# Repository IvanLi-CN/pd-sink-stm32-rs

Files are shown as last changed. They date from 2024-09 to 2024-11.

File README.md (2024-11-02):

# VoltageSpy

## Project Overview

VoltageSpy is a versatile power analysis tool, integrating a USB-PD (Power Delivery) emulator and real-time current, voltage, and power display functionality.

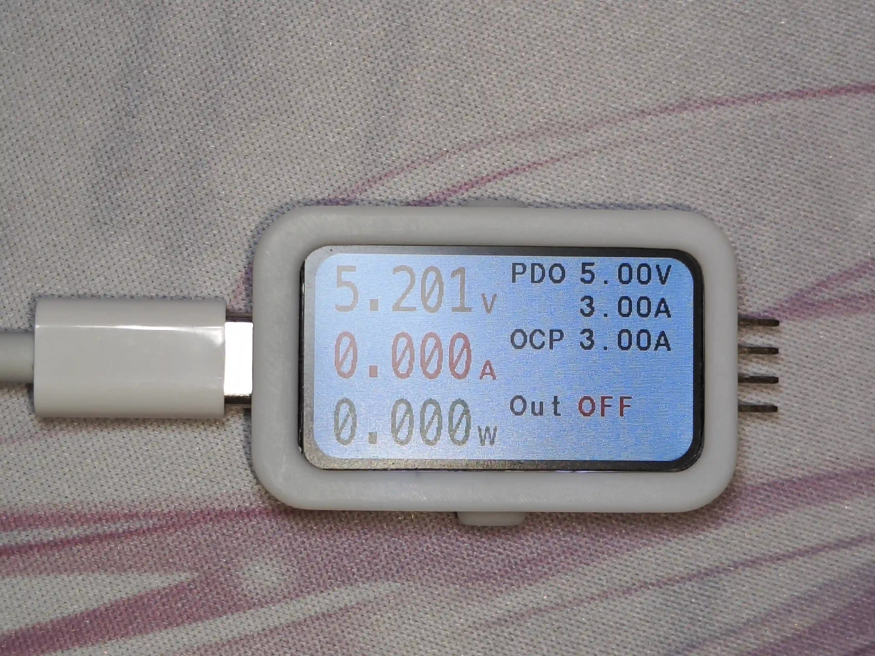
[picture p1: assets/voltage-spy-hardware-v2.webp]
hardware-v2


Originally intended for testing my other USB-C power project, this device can also serve as a temporary power supply tool. It supports voltage requests of 5V, 9V, 12V, 15V, 18V, and 20V.

The project is currently functional, but there are some additional features that I haven't had time to implement yet.

## Key Features

1. **PD Emulator**: Simulates various PD devices for testing and developing USB-C PD chargers and devices.
2. **Real-Time Display**: High-precision real-time monitoring and display of current, voltage, and power data.
3. **Overcurrent Protection**: Supports software overcurrent protection.
4. **Multi-Protocol Support**: In addition to PD, it also supports QC (Quick Charge) and other fast-charging protocols.

TODO:

- [ ] PWM Output
- [ ] Settings Memory (considering adding an EEPROM to achieve this)

## Technical Specifications

- Input Voltage Range: 0-20V
- Current Measurement Range: 0-5A
- Power Measurement Range: 0-100W
- Display: 1.47-inch TFT display (ST7789)
- Interface: USB-C -> 2.54mm pitch pin header
- Dimensions: 46mm x 26mm x 8.5mm

- Main Controller: STM32G071GBU6
- PD Sink Chip: HUSB238
- Current Sensor: INA226

- Firmware developed with Rust + embassy-stm32

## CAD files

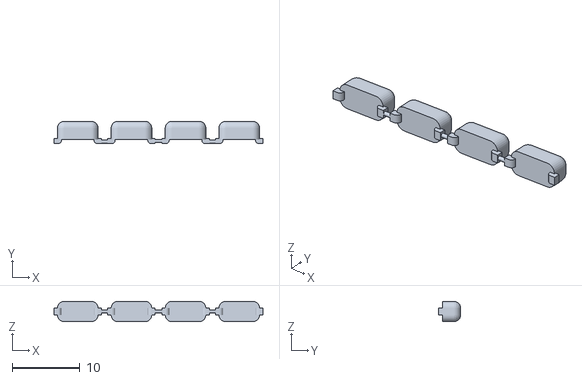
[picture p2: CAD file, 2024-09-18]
models/PDSinkShell-FourBtns.stl
30.8 x 3.30 x 3.00

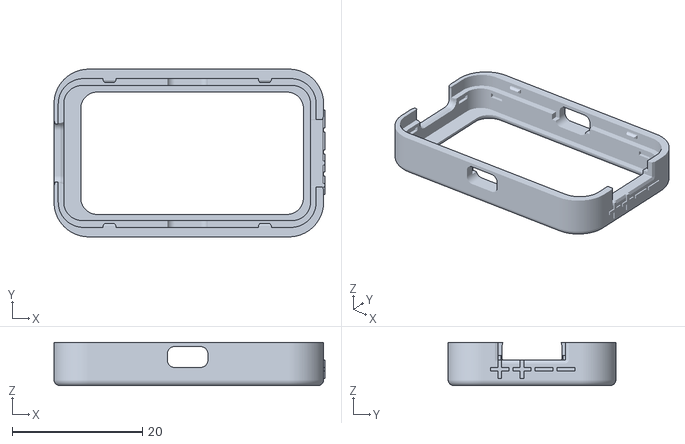
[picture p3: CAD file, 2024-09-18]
models/PDSinkShell-FrontCoverFusion.stl
41.6 x 25.7 x 6.64

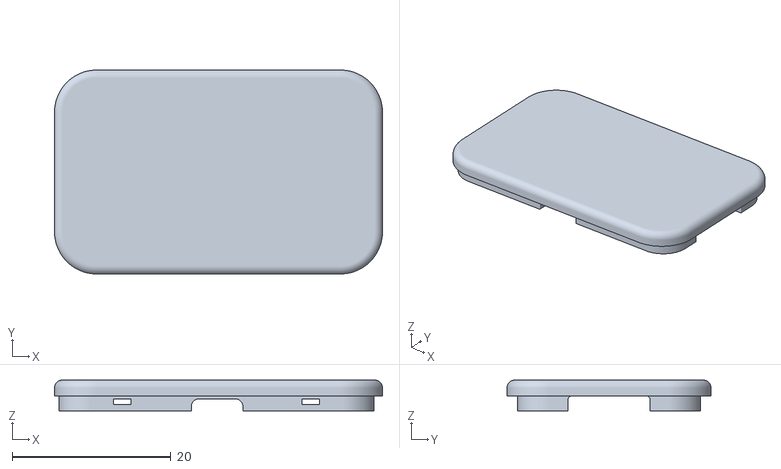
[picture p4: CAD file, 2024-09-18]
models/PDSinkShell-BackCover.stl
41.4 x 25.7 x 3.90

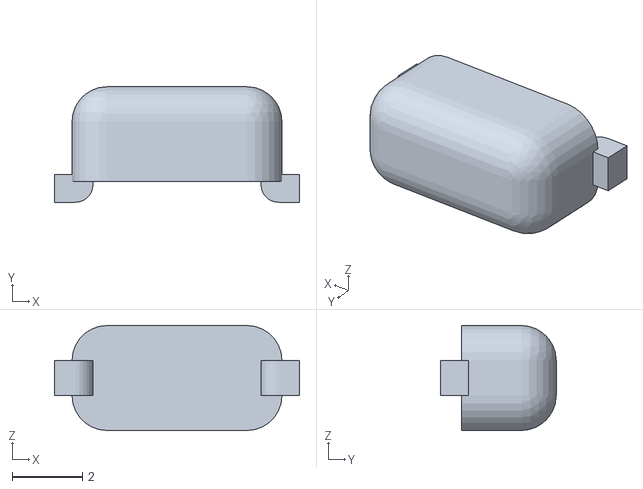
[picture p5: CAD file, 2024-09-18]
models/PDSinkShell-Button.stl
7.00 x 3.30 x 3.00

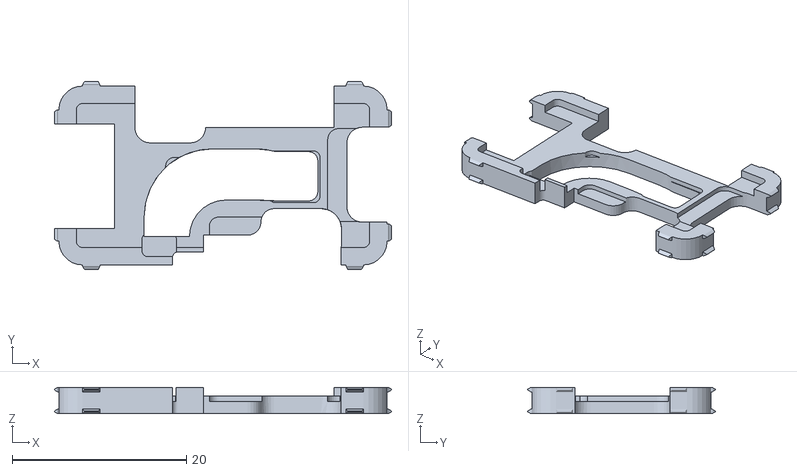
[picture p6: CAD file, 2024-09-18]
models/PDSinkShell-MiddleSpacer.stl
38.7 x 21.5 x 3.00

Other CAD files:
models/PDSinkShell-Button_Copy.stl

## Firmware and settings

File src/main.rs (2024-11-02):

#![no_std]
#![no_main]

use button::Button;
use combined_filter::CombinedFilter;
use controller::Controller;
use display::Display;
use embassy_embedded_hal::shared_bus::{
    asynch::{i2c::I2cDevice, spi::SpiDevice},
    I2cDeviceError,
};
use embassy_executor::Spawner;
use embassy_futures::select::{select3, Either3};
use embassy_stm32::{
    bind_interrupts,
    exti::ExtiInput,
    gpio::{Level, Output, OutputType, Pull, Speed},
    i2c::{self, I2c},
    mode, peripherals,
    spi::{self, Spi},
    time::{khz, Hertz},
    timer::simple_pwm::{PwmPin, SimplePwm},
};
use embassy_sync::{blocking_mutex::raw::CriticalSectionRawMutex, mutex::Mutex};

use defmt_rtt as _;
use embassy_time::{Duration, Ticker};
use husb238::{Command, Husb238};
use ina226::{DEFAULT_ADDRESS, INA226};
use output_controller::OutputController;
// global logger
use panic_probe as _;

use shared::{
    AVAILABLE_VOLT_CURR_MUTEX, BTN_A_STATE_CHANNEL, BTN_B_STATE_CHANNEL, DISPLAY, OCP_MUTEX,
    PDO_PUBSUB,
};
use st7789::{self, ST7789};
use static_cell::StaticCell;
use types::{AvailableVoltCurr, ST7789Display, SpiBus};

mod button;
mod controller;
mod display;
mod exponential_moving_average;
mod font;
mod output_controller;
mod shared;
mod types;
mod combined_filter;

static SPI_BUS_MUTEX: StaticCell<Mutex<CriticalSectionRawMutex, SpiBus>> = StaticCell::new();
static HUSB238_I2C_MUTEX: StaticCell<Mutex<CriticalSectionRawMutex, I2c<'_, mode::Async>>> =
    StaticCell::new();

bind_interrupts!(struct Irqs {
    I2C1 => i2c::EventInterruptHandler<peripherals::I2C1>, i2c::ErrorInterruptHandler<peripherals::I2C1>;
});

// This marks the entrypoint of our application.

#[embassy_executor::main]
async fn main(spawner: Spawner) {
    let p = embassy_stm32::init(Default::default());

    defmt::println!("Hello, world!");

    let out_ctl_pin = Output::new(p.PA8, Level::Low, Speed::Low);
    let mut output_controller = OutputController::new(out_ctl_pin);

    let mut config = spi::Config::default();
    config.frequency = Hertz(16_000_000);
    let spi = Spi::new_txonly(p.SPI1, p.PA5, p.PA7, p.DMA1_CH1, config); // SCK is unused.
    let spi: Mutex<CriticalSectionRawMutex, _> = Mutex::new(spi);
    let spi = SPI_BUS_MUTEX.init(spi);

    // init display

    let cs_pin = Output::new(p.PA4, Level::High, Speed::High);
    let dc_pin = Output::new(p.PA15, Level::Low, Speed::High);
    let rst_pin = Output::new(p.PA12, Level::Low, Speed::High);

    let spi_dev = SpiDevice::new(spi, cs_pin);

    let st7789: ST7789Display = ST7789::new(st7789::Config::default(), spi_dev, dc_pin, rst_pin);
    let mut _display = Display::new(st7789);

    _display.init().await.unwrap();

    let mut display = DISPLAY.lock().await;
    *display = Some(_display);
    drop(display);

    // init backlight

    let blk_pin = PwmPin::new_ch3(p.PB6, OutputType::PushPull);

    let mut blk_tim = SimplePwm::new(
        p.TIM1,
        None,
        None,
        Some(blk_pin),
        None,
        khz(1),
        embassy_stm32::timer::low_level::CountingMode::EdgeAlignedUp,
    );

    blk_tim.ch3().enable();
    blk_tim.ch3().set_duty_cycle_percent(50);

    let i2c = I2c::new(
        p.I2C1,
        p.PB8,
        p.PB7,
        Irqs,
        p.DMA1_CH3,
        p.DMA1_CH4,
        Hertz(100_000),
        Default::default(),
    );

    let i2c = Mutex::new(i2c);
    let i2c = HUSB238_I2C_MUTEX.init(i2c);

    // init ina226

    let i2c_dev = I2cDevice::new(&i2c);
    let mut ina226 = INA226::new(i2c_dev, DEFAULT_ADDRESS);
    ina226
        .set_configuration(&ina226::Config {
            mode: ina226::MODE::ShuntBusVoltageContinuous,
            avg: ina226::AVG::_1,
            vbusct: ina226::VBUSCT::_1100us,
            vshct: ina226::VSHCT::_1100us,
        })
        .await
        .unwrap();

    ina226.callibrate(0.01, 5.0).await.unwrap();

    // init buttons

    let button_a = ExtiInput::new(p.PC14, p.EXTI14, Pull::Up);
    let button_b = ExtiInput::new(p.PB0, p.EXTI0, Pull::Up);

    spawner.spawn(controller_exec()).ok();
    spawner.spawn(btns_exec(button_a, button_b)).ok();

    let i2c_dev = I2cDevice::new(i2c);
    let mut husb238 = Husb238::new(i2c_dev);

    {
        let mut available_volt_curr = AVAILABLE_VOLT_CURR_MUTEX.lock().await;

        *available_volt_curr = get_available_volt_curr(&mut husb238).await.unwrap();
    }

    let mut pdo_sub = PDO_PUBSUB.subscriber().unwrap();

    let mut count = 0u8;

    let mut amps_avg = CombinedFilter::new(0.1);
    let mut volts_avg = CombinedFilter::new(0.1);
    let mut watts_avg = CombinedFilter::new(0.1);

    loop {
        let mut display = DISPLAY.lock().await;

        if display.is_none() {
            continue;
        }
        let display = display.as_mut().unwrap();

        output_controller.task().await;
        display.task().await;

        match ina226.bus_voltage_millivolts().await {
            Ok(val) => {
                display.update_monitor_volts(volts_avg.update(val / 1000.0)).await;
            }
            Err(_) => {
                display.update_monitor_volts(99999.99999).await;
            }
        }

        let ocp_guard = OCP_MUTEX.lock().await;
        let ocp = *ocp_guard;

        display.update_ocp_amps(ocp).await;


        match ina226.current_amps().await {
            Ok(val) => {
                let amps = val.unwrap_or(0.0).max(0.0);

                if amps > ocp {
                    output_controller.set_output(false).await;
                    display.update_output(false).await;
                    display.update_monitor_amps(amps).await;
                } else {
                    display.update_monitor_amps(amps_avg.update(amps)).await;
                }
            }
            Err(_) => {
                display.update_monitor_amps(99999.99999).await;
            }
        }

        match ina226.power_watts().await {
            Ok(val) => {
                let watts = val.unwrap_or(0.0);

                display.update_monitor_watts(watts_avg.update(watts)).await;
            }
            Err(_) => {
                display.update_monitor_watts(99999.99999).await;
            }
        }

        let changed_pdo = pdo_sub.try_next_message_pure();

        if changed_pdo.is_none() {
            count += 1;
            if count < 10 {
                continue;
            }
        } else {
            match husb238.set_src_pdo(changed_pdo.unwrap()).await {
                Ok(_) => {
                    match husb238.go_command(Command::Request).await {
                        Ok(_) => {
                            count = 0;
                        }
                        Err(_) => {
                            defmt::error!("go command error");
                        }
                    }
                    defmt::info!("set src_pdo: {:?}", changed_pdo.unwrap());
                }
                Err(_) => {
                    defmt::error!("set src_pdo error");
                }
            }
        }

        count = 0;

        match husb238.get_actual_voltage_and_current().await {
            Ok((volts, amps)) => {
                display.update_target_volts(volts.unwrap_or(0.0)).await;
                display.update_limit_amps(amps).await;
            }
            Err(_) => {
                defmt::error!("get actual voltage and current error");
            }
        }

        // Timer::after(Duration::from_millis(1000)).await;
    }
}

async fn get_available_volt_curr<'a>(
    husb238: &mut Husb238<I2cDevice<'a, CriticalSectionRawMutex, I2c<'static, mode::Async>>>,
) -> Result<AvailableVoltCurr, I2cDeviceError<i2c::Error>> {
    Ok(AvailableVoltCurr {
        _5v: husb238.get_5v_status().await?,
        _9v: husb238.get_9v_status().await?,
        _12v: husb238.get_12v_status().await?,
        _15v: husb238.get_15v_status().await?,
        _18v: husb238.get_18v_status().await?,
        _20v: husb238.get_20v_status().await?,
    })
}

#[embassy_executor::task]
async fn btns_exec(mut btn_a: ExtiInput<'static>, mut btn_b: ExtiInput<'static>) {
    let mut button_a = Button::new(&BTN_A_STATE_CHANNEL);
    let mut button_b = Button::new(&BTN_B_STATE_CHANNEL);

    loop {
        let btn_a_change = btn_a.wait_for_any_edge();

        let btn_b_change = btn_b.wait_for_any_edge();

        let mut ticker = Ticker::every(Duration::from_millis(100));

        let futures = select3(btn_a_change, btn_b_change, ticker.next());

        match futures.await {
            Either3::First(_) => {
                if btn_a.is_high() {
                    button_a.on_release().await;
                } else {
                    button_a.on_press().await;
                }
            }
            Either3::Second(_) => {
                if btn_b.is_high() {
                    button_b.on_release().await;
                } else {
                    button_b.on_press().await;
                }
            }
            Either3::Third(_) => {
                button_a.update().await;
                button_b.update().await;
            }
        };
    }
}

#[embassy_executor::task]
async fn controller_exec() {
    let mut controller = Controller::new();

    controller.task().await;
}

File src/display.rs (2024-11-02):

use core::convert::Infallible;

use embassy_sync::{blocking_mutex::raw::CriticalSectionRawMutex, pubsub::Subscriber};
use embedded_graphics::{pixelcolor::Rgb565, prelude::WebColors};
use embedded_hal::digital::OutputPin;
use embedded_hal_async::spi::SpiDevice;
use husb238::SrcPdo;
use st7789::ST7789;

use crate::{
    font::{
        get_index_by_char, ARIAL_ROUND_16_24, ARIAL_ROUND_16_24_INDEX, GROTESK_24_48,
        GROTESK_24_48_INDEX,
    },
    shared::{
        AVAILABLE_VOLT_CURR_MUTEX, COLOR_AMPERAGE, COLOR_BACKGROUND, COLOR_BASE, COLOR_OFF_TEXT, COLOR_ON_TEXT, COLOR_PRIMARY, COLOR_PRIMARY_CONTENT, COLOR_TEXT, COLOR_TEXT_DISABLED, COLOR_VOLTAGE, COLOR_WATTAGE, DISPLAY_DIRECTION_PUBSUB, OUTPUT_PUBSUB, PAGE_PUBSUB
    },
    types::{
        Direction, Page, PowerInfo, SettingItem, StatusInfo, OCP_ITEMS, SETTING_ITEMS,
        VOLTAGE_ITEMS,
    },
};

const MONITOR_PRIMARY_X: u16 = 14;
const MONITOR_PRIMARY_Y1: u16 = 6;
const MONITOR_PRIMARY_Y2: u16 = 62;
const MONITOR_PRIMARY_Y3: u16 = 118;
const MONITOR_PRIMARY_UINT_X: u16 = 138;
const MONITOR_PRIMARY_UINT_Y1: u16 = 30;
const MONITOR_PRIMARY_UINT_Y2: u16 = 86;
const MONITOR_PRIMARY_UINT_Y3: u16 = 142;
const MONITOR_SECONDARY_X1: u16 = 164;
const MONITOR_SECONDARY_X2: u16 = 222;
const MONITOR_SECONDARY_X3: u16 = 286;
const MONITOR_SECONDARY_Y1: u16 = 4;
const MONITOR_SECONDARY_Y2: u16 = 32;
const MONITOR_SECONDARY_Y3: u16 = 60;
const MONITOR_SECONDARY_Y4: u16 = 88;
const MONITOR_SECONDARY_Y5: u16 = 116;
const MONITOR_SECONDARY_Y6: u16 = 144;

pub struct Display<'a, SPI, DC, RST>
where
    SPI: SpiDevice,
    DC: OutputPin<Error = Infallible>,
    RST: OutputPin<Error = Infallible>,
{
    st7789: ST7789<SPI, DC, RST>,
    power_info: PowerInfo,
    status_info: StatusInfo,
    ryu_buffer: ryu::Buffer,
    prev_ryu_buffer: ryu::Buffer,
    force_render: bool,

    page: Page,
    direction: Direction,
    output: bool,

    page_sub: Subscriber<'a, CriticalSectionRawMutex, Page, 2, 2, 1>,
    direction_sub: Subscriber<'a, CriticalSectionRawMutex, Direction, 2, 2, 1>,
    output_sub: Subscriber<'a, CriticalSectionRawMutex, bool, 2, 2, 1>,
}

impl<'a, SPI, DC, RST> Display<'a, SPI, DC, RST>
where
    SPI: SpiDevice,
    DC: OutputPin<Error = Infallible>,
    RST: OutputPin<Error = Infallible>,
{
    pub fn new(st7789: ST7789<SPI, DC, RST>) -> Self {
        Self {
            st7789,
            power_info: PowerInfo::default(),
            status_info: StatusInfo::default(),
            ryu_buffer: ryu::Buffer::new(),
            prev_ryu_buffer: ryu::Buffer::new(),
            force_render: true,

            page: Page::Monitor,
            direction: Direction::Normal,
            output: false,

            page_sub: PAGE_PUBSUB.subscriber().unwrap(),
            direction_sub: DISPLAY_DIRECTION_PUBSUB.subscriber().unwrap(),
            output_sub: OUTPUT_PUBSUB.subscriber().unwrap(),
        }
    }

    async fn reinit(&mut self) -> Result<(), ()> {
        self.force_render = true;

        self.st7789
            .set_orientation(match self.direction {
                Direction::Normal => st7789::Orientation::Landscape,
                Direction::Reversed => st7789::Orientation::LandscapeSwapped,
            })
            .await
            .map_err(|_| ())?;

        self.update_layout().await;

        self.force_render = false;
        Ok(())
    }

    pub async fn init(&mut self) -> Result<(), ()> {
        self.st7789.init().await.map_err(|_| ())?;

        self.reinit().await
    }

    pub async fn update_monitor_volts(&mut self, volts: f64) {
        if !matches!(self.page, Page::Monitor) {
            return;
        }

        let curr = self.ryu_buffer.format(volts);
        let prev = self.prev_ryu_buffer.format(self.power_info.volts);

        Self::render_monitor(
            &mut self.st7789,
            curr,
            prev,
            MONITOR_PRIMARY_Y1,
            COLOR_BACKGROUND,
            COLOR_VOLTAGE,
            self.force_render,
        )
        .await;

        self.power_info.volts = volts;
    }

    pub async fn update_monitor_amps(&mut self, amps: f64) {
        if !matches!(self.page, Page::Monitor) {
            return;
        }

        let amps = if amps < 0.0001 { 0.0 } else { amps };
        let curr = self.ryu_buffer.format(amps);
        let prev = self.prev_ryu_buffer.format(self.power_info.amps);

        Self::render_monitor(
            &mut self.st7789,
            curr,
            prev,
            MONITOR_PRIMARY_Y2,
            COLOR_BACKGROUND,
            COLOR_AMPERAGE,
            self.force_render,
        )
        .await;

        self.power_info.amps = amps;
    }

    pub async fn update_monitor_watts(&mut self, watts: f64) {
        if !matches!(self.page, Page::Monitor) {
            return;
        }

        let watts = if watts < 0.0001 { 0.0 } else { watts };
        let curr = self.ryu_buffer.format(watts);
        let prev = self.prev_ryu_buffer.format(self.power_info.watts);

        Self::render_monitor(
            &mut self.st7789,
            curr,
            prev,
            MONITOR_PRIMARY_Y3,
            COLOR_BACKGROUND,
            COLOR_WATTAGE,
            self.force_render,
        )
        .await;

        self.power_info.watts = watts;
    }

    pub async fn update_target_volts(&mut self, volts: f64) {
        if !matches!(self.page, Page::Monitor) {
            return;
        }

        if self.status_info.target_volts == volts && !self.force_render {
            return;
        }

        self.status_info.target_volts = volts;

        let curr = self.ryu_buffer.format(self.status_info.target_volts);

        Self::render_status(
            &mut self.st7789,
            curr,
            MONITOR_SECONDARY_X2,
            MONITOR_SECONDARY_Y1,
            COLOR_BACKGROUND,
            COLOR_TEXT,
            4,
        )
        .await;
    }

    pub async fn update_limit_amps(&mut self, amps: f64) {
        if !matches!(self.page, Page::Monitor) {
            return;
        }

        if self.status_info.limit_amps == amps && !self.force_render {
            return;
        }

        self.status_info.limit_amps = amps;

        let curr: &str = self.ryu_buffer.format(self.status_info.limit_amps);

        Self::render_status(
            &mut self.st7789,
            curr,
            MONITOR_SECONDARY_X2,
            MONITOR_SECONDARY_Y2,
            COLOR_BACKGROUND,
            COLOR_TEXT,
            4,
        )
        .await;
    }

    pub async fn update_ocp_amps(&mut self, amps: f64) {
        if !matches!(self.page, Page::Monitor) {
            return;
        }

        if self.status_info.ocp_amps == amps && !self.force_render {
            return;
        }

        self.status_info.ocp_amps = amps;

        let curr: &str = self.ryu_buffer.format(self.status_info.ocp_amps);
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

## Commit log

2024-08-31 feat(hardware): migrate to embassy-stm32 and add display support
    Implement major changes to the project structure and dependencies:
    - Switch from stm32-hal2 to embassy-stm32 for hardware abstraction
    - Add ST7789 display driver and initialization
    - Implement basic display functionality with color filling
    - Update GPIO and SPI configurations for the new HAL
    - Modify main loop to toggle LED and update display colors
    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
2024-08-31 refactor(display): update ST7789 display initialization and configuration
    Update the ST7789 display driver initialization sequence and default
    configuration to better match the specific display hardware being used.
    - Update initialization commands and parameters for ST7789 display
    - Increase SPI frequency from 4MHz to 16MHz for faster communication
    - Add default configuration for the display with 320x172 resolution
    - Remove unused gamma control commands
    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
2024-09-14 chore: migrating to STM32G071GBU8 for more flash space.
2024-09-18 feat: add feature to display sink voltage and current information
2024-09-18 feat: add 3D shell model
    [PDSinkShell-BackCover.stl, PDSinkShell-Button.stl, PDSinkShell-Button_Copy.stl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]
2024-09-18 feat: implement PWM backlight control for display
2024-09-18 feat: capture button event
2024-09-19 feat: parse button output
2024-10-06 feat: voltage setting.
2024-10-06 fix(display): restore data when returning to monitoring page
    Implement data restoration when navigating back to the monitoring page.
    This change ensures that all relevant information is displayed correctly,
    including amperage, voltage, wattage, target voltage, current limit, and
    output status.
    - Update monitor layout and force render all components
    - Reset force render flag after updating all elements
    Resolves issue with data loss when returning to the monitoring page.
    [display.rs]
2024-10-06 feat(controller): add shortcut to return to monitoring screen
    Implement a new feature allowing users to quickly return to the monitoring
    screen from the voltage setting screen by pressing and holding both the up
    and down buttons simultaneously.
    - Add handling for BtnsState::UpAndDownLong in the voltage setting screen
    - Update the page state to Monitor
    - Publish the new page state
    - Update and publish the PDO (Programmable Power Supply Output) state
    This feature improves user experience by providing a faster way to exit
    the voltage setting screen.
2024-10-23 chore(deps): update embassy crates to latest git version
    Update embassy-related dependencies to use the latest git version from
    the main branch instead of specific versions. This includes:
    - embassy-embedded-hal
    - embassy-executor
    - embassy-futures
    - embassy-stm32
    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
2024-11-02 feat(filter): introduce CombinedFilter for signal processing
    Add a new `CombinedFilter` struct that integrates median and low-pass
    filtering to enhance signal processing accuracy. This implementation
    replaces the previous `ExponentialMovingAverage` with a more robust
    filtering mechanism in the main application logic.
    - Implemented median filtering using insertion sort for windowed data.
    - Applied low-pass filtering to smooth the output.
    - Updated display logic to utilize the new filter for voltage,
    current, and power readings.
    This change improves the system's ability to handle noise and
    transients in signal measurements.
    [display.rs, main.rs]
